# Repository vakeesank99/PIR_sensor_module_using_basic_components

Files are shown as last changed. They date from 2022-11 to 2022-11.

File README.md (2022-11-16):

# PIR_sensor_module_using_basic_components

I try to make the PIR sensor module without using the commercial IC which has all the functionality such as normal-mode, re-triggering and turned on only at the dark environment. This is very hard to understand the real concept behind each task as well as their implementation. But somehow we managed to proceed with all their required functionalities using transistors, OPAM and basic components. 

### Here is the schematic

Signal conditioning unit

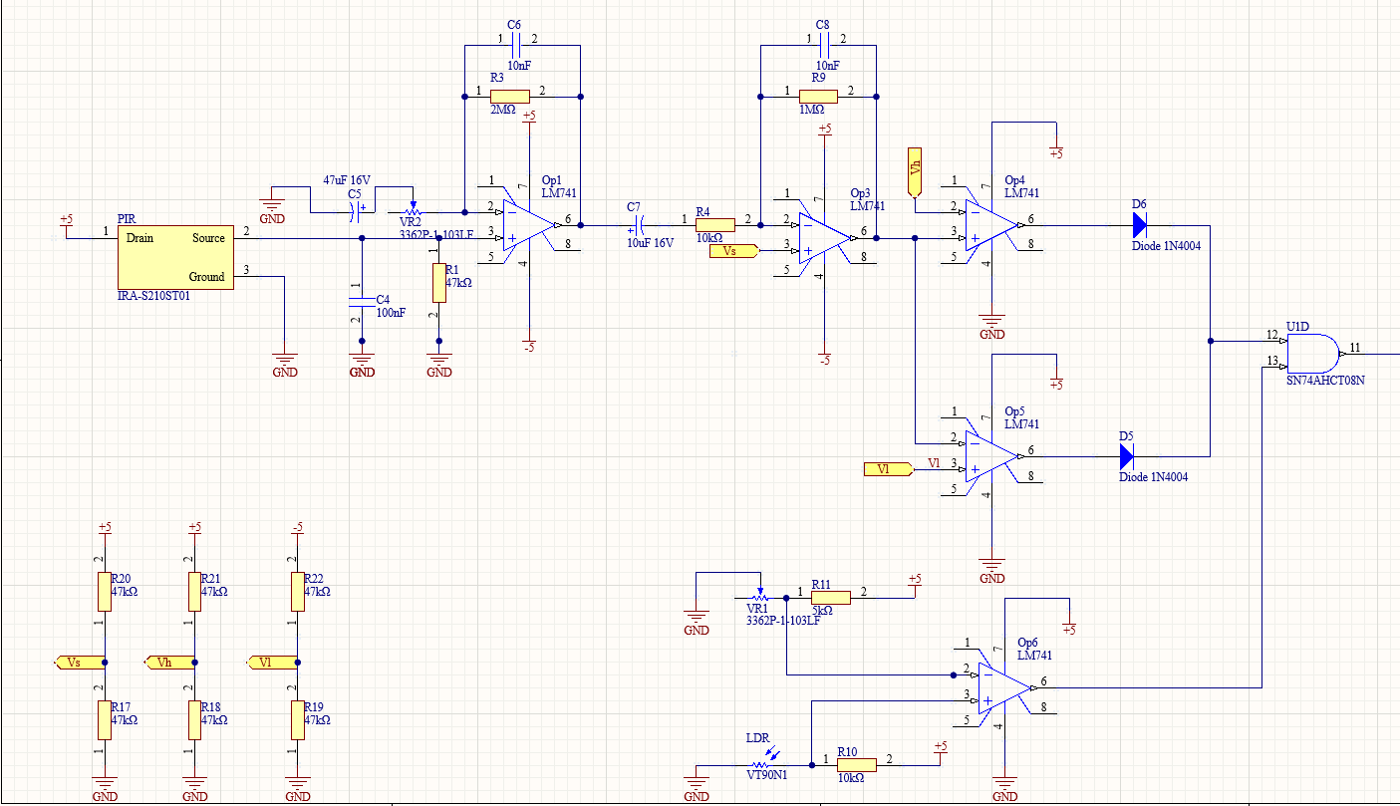
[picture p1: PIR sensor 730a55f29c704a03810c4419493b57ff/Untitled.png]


Decision making unit

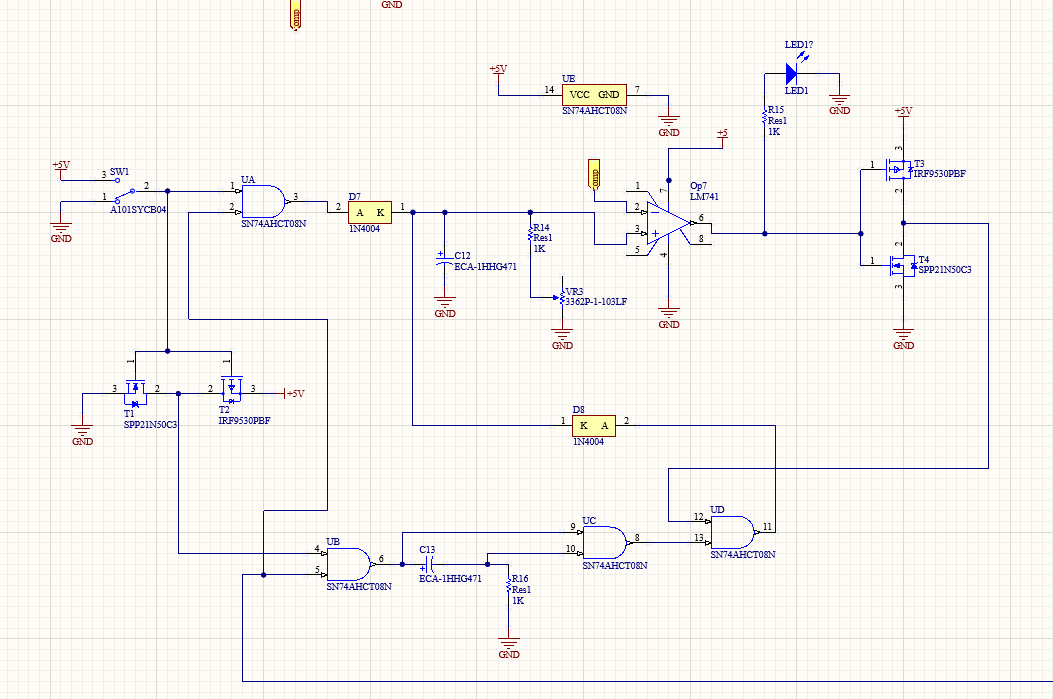
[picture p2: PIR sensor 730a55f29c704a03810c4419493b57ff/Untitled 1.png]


### Here is the final PCB after soldered the components.

Front



Back



### Appendix

Pyroelectric infrared sensors, IRA series, exhibit high
sensitivity and reliable performance made possible by
Murata's ceramic technology and Hybrid IC technique
expertise developed over many years.

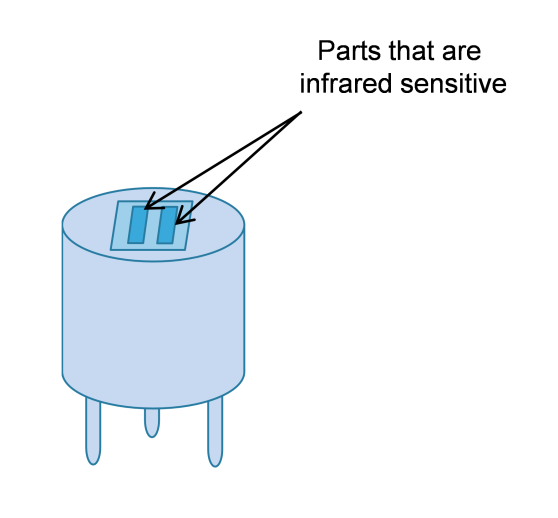
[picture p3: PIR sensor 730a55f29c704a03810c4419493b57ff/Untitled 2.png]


How does the PIR sensor work
The aim of the PIR sensor is to detect motion in a specific area. As seen in Figure 1: "PIR
sensor", these sensors contain two parts that are sensitive to IR. Since it is motion that is
important, the signal delivered by the sensor reflects different amounts of IR detected by
each part. If both parts "see" the same amount of IR, the sensor detects nothing. But, if one
of the two parts "sees" more or less IR than the other part, the sensor detects something
and the output voltage of the sensor varies.
Figure 2 shows how the output voltage varies when a heat source moves in or out of the
area protected by a sensor.

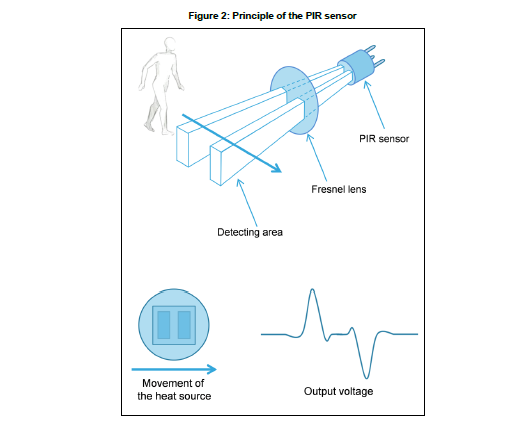
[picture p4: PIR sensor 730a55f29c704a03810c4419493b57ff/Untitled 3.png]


The area of the two rectangles that is IR sensitive is small (≈2 mm² for each rectangle).
Clearly, it would be better to increase the IR sensitive area. This can be done in two ways:
- by increasing the number of sensors
- by using a Fresnel lens
The latter method is highly recommended as it is inexpensive and improves IR reception by
the sensor. It multiplies the area visible to the sensor and it focuses reception of IR by the
sensor.

Three-stage architecture for detecting motion
To detect motion, a three-stage architecture based on op-amps is used to condition the
signal of a PIR sensor. This architecture is explained below.

### Stage 1
The first architectural stage amplifies the signal. It cancels the DC part of the signal and
filters the high frequency noise that could lead to false detections. The schematic of this
first architectural stage is shown in Figure 3.

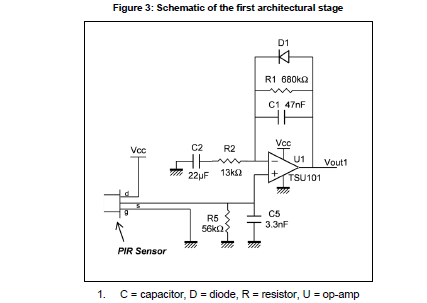
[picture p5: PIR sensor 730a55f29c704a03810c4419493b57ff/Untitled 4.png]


Figure 3 shows that noise is filtered thanks to the components R1 and C1. The cut-off
frequency is 5 Hz (fhigh1 = 1/(2 x π x R1 x C1)). This application does not need to work at
higher frequencies because usually we are detecting human motion.
The second filter is used to reject the DC part of the signal. R2 and C2 perform a high pass
filter that has a cut-off frequency of 0.6 Hz (flow1 = 1/(2 x π x R2 x C2)).
Since we do not amplify the DC part of the signal, the Vio, which is the input offset voltage
of the op-amp, has no importance in this application.
The stage gain is 53.3 (Gain1 = 1 + R1/R2). This amplification allows a usable signal that is
higher than the noise level. The DC bias of the first architectural stage is determined by the
sensor. To avoid saturation, the gain must not be too big because amplification is made
around this common mode voltage (which is not Vcc/2).
STMicroelectronics’ TSU101 op-amp is a perfect fit for this architectural stage. As well as
having very low consumption, the TSU101 operates with a typical current consumption of
only 600 nA at Vcc = 3.3 V.
The diode, D1, is explained in Section 5: "Power-up".

### Stage 2

Stage 2 is very similar to stage 1 (see Figure 4). It is used to filter and amplify the AC
signal.

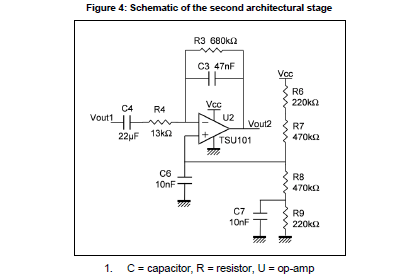
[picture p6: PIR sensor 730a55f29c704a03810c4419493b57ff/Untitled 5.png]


Regarding the filtering function, the low and high cut-off frequencies respectively are 0.6 Hz
(flow2 = 1/(2 x π x R4 x C4)) and 5 Hz (fhigh2 = 1/(2 x π x R3 x C3)). The gain of this stage is
-52.3 (Gain2 = -R3/R4). This gain means that after stage 2 the signal between 0.6 Hz and
5 Hz will have been amplified 2790 times (69 dB).
In stage 2, the op-amp common mode voltage is set by the divider bridge composed of R6,
R7, R8, and R9 to Vcc/2. This allows greater amplification of the AC signal.
As with stage 1, the Vio of the op-amp has no importance since the DC part of the signal is
not amplified. Moreover, there is no constraint on the gain bandwidth product (GBP),
because the op-amp has to have a GBP greater than 2.6 kHz (fhigh2 x gain x 10). A factor of
10 has been used to avoid any limitations by the GBP. Almost all GBP amplifiers fit this
2.6 kHz requirement.
The TSU101 op-amp is very suitable for this architectural stage. Its low consumption is
particularly advantageous. Although it is a nanopower op-amp, its GBP is higher than
2.6 kHz. Note that TSU101 is also available in dual (TSU102) and quad (TSU104) channel
versions to optimize the footprint on board.

### Stage 3

The third and last architectural stage allows the user to perform a window comparator. As a
consequence, the signal is perfectly conditioned to go to a microcontroller. Figure 5 shows
the schematic of this stage.

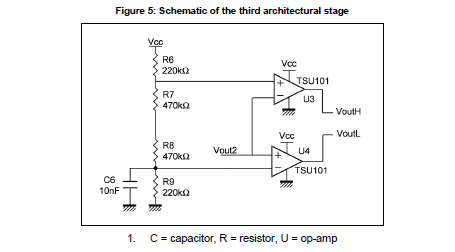
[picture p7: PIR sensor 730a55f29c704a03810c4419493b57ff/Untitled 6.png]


When a heat source is detected, the output of the op-amp U3 and/or U4 is in low state. The
divider bridge, composed of the resistors R6, R7, R8, and R9, is used to set the voltage
reference of these devices. The TSU101 op-amp is an input/output rail to rail op-amp, and
there is no constraint on the input common mode voltage. Thus, while the voltage
references of U3 and U4 are within the Vcc range the window comparator works.
For the following example, the reference of U3 is set to 0.84 * Vcc:



When the signal (Vout2) is above this reference (2.77 V if Vcc = 3.3 V), the output of U3 is
in low state, close to ground.
U4 is used to detect when the signal is below a certain reference. In this example, the
voltage reference is set to 530 mV thanks to the divider bridge composed of R6, R7, R8, and
R9. The voltage reference calculation is:



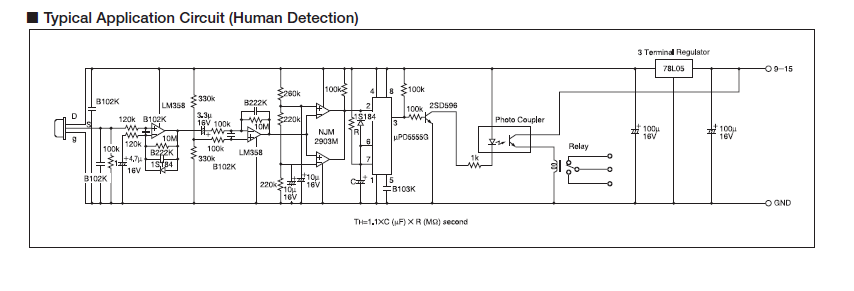
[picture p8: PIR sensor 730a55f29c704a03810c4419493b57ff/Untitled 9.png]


window comparator

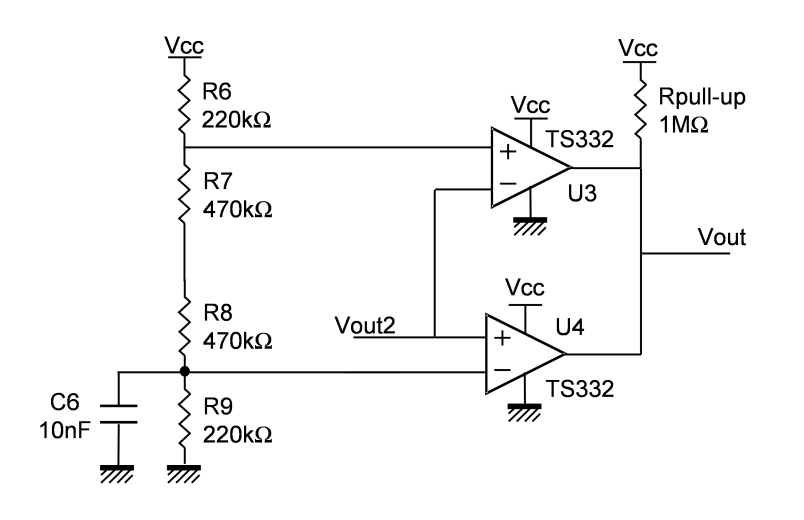
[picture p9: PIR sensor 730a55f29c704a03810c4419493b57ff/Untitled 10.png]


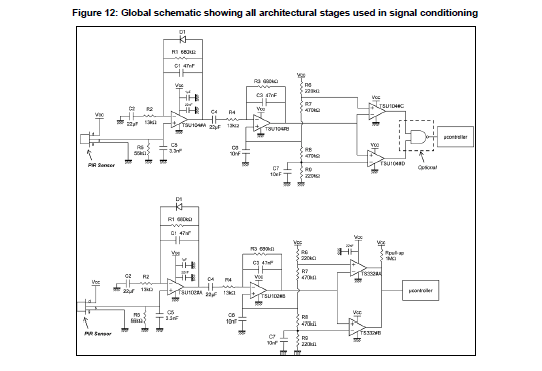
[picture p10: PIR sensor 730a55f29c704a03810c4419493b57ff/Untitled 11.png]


offset null procedure

[https://www.youtube.com/watch?v=5ExpeE_YOwQ](https://www.youtube.com/watch?v=5ExpeE_YOwQ)

[https://www.youtube.com/watch?v=Ut-m8dl7INA](https://www.youtube.com/watch?v=Ut-m8dl7INA)

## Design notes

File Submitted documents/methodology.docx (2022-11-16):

Methodology

Amplifier part

when there is an object with a temperature different than ambient temperature, is moving in front of the PIR sensor which emits a small Ac signal around 1 mVpp. as our task to detect the human motion, we need to consider the frequencies from 0.5 Hz to 10 Hz. further more that signal will be around a DC level which is significant sensor to sensors.

therefore, it is mandatory to cancel out the DC part of the signal then the AC part of the signal should be amplified. As the signal has the environment effect, Nosie filtering will be useful as well. the Op amps are very helpful to achieve for all these functions. we can divide the amplifier part into four sub parts.

stage 01

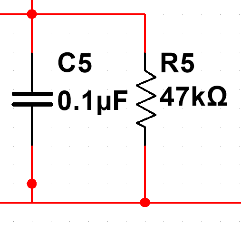
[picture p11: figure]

from the PIR sensor

to the op amp 1

At the first PIR sensor’s signal will go through the C5, R5 (first order filter). here we can see that it will act like an LPF (Low Pass Filter). therefore, there will be an upper cut off frequency which can be calculated as below.

f_(upper cut off) =1/(2πR_5 C_5)=1/(2π×47 kΩ ×0.1 μF)≈34 Hz

As we have already known that our final task is to detect the human motion which is around 10 Hz such that it’s approximately taken the 34 Hz as the upper cut off which is not harm. Other than that, we can simply avoid the high frequency noises (not thoroughly) as well as the environmental effects at this simple stage.

stage 02

After that our signal will enter in to the next stage where we can cancel out the DC component by a capacitor. the smoothing circuit will get rid of the high frequency noise as well as, give the variable gain to accommodate the sensitivity at a certain level.

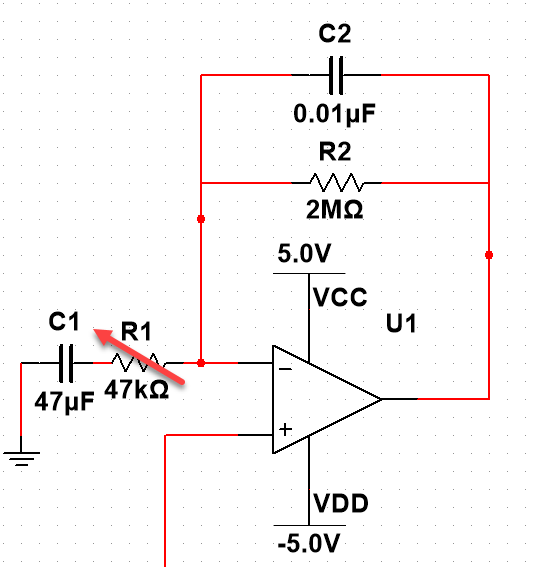
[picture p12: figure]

from the LPF part

to the op amp 2

as it’s explained above, C1 will cancel out the DC components from the sensor and allows the AC components of the signal. the value of the capacitor is taken same as the C5 in previous discussion without any particular reasoning. there will be a lower cut off value for the smoothing filter which can be calculated as shown below.

f_(lower cut off) =1/(2πR_2 C_2)=1/(2π×2 MΩ ×0.01 μF)≈8 Hz

According to the bode plot of the integrator circuit of the op amp, amplitude will be decreasing and smoothing will be started at the lower cut off point. it is calculated that at around 8 Hz circuit starts the smoothing functionality as well as the amplitude of the output signal is high (our requirement is at 10Hz so, no issues). Furthermore, as it’s mentioned earlier the gain of the is first op amp can be adjustable as shown below.

A_(op1) =-(R2)/(R1)

it is possible to set this gain as constant if we don’t want the distance as a variable. Such that it is assumed to set the gain from the first op amp as ~40. furthermore, R2 can be easily got from the R5 value and R2

R_5 =R_1 |R_2 =47 kΩ |2 MΩ≈47kΩ

but this value is only valid for the object which is moving nearby (< ~ 50cm) the PIR sensor. such that when it is increased to detect the object far from the previous value. therefore, the potentiometer value is selected as 1M ohm (quite reasonable). Furthermore, our input is an AC signal such that we have to supply a negative voltage to the op amp.

stage 03

After this part our signal again enter into a capacitor in order to avoid any DC components coming out from the op amp 1. Moreover, C3 is also chosen same as the previous discussion.

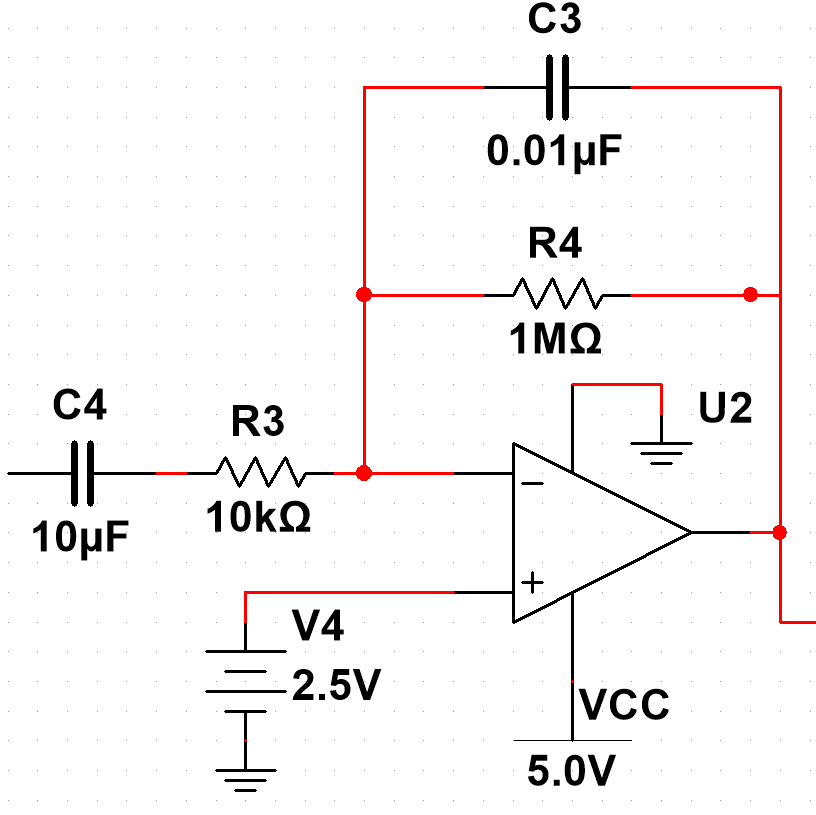
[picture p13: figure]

from the op amp 1

to the window comparator

In this circuit we can simply increase the gain by another amount. That can be calculated as below.

A_(op2) =-(R_4)/(R_3)=-(1MΩ)/(10kΩ)=-100

such that the total gain can be calculated by multiplying the two gain values. this is very important for the proper selection of R1 in the first op amp as well as maintaining the peak to peak amplitude of the signal at |2.5V| for the next stage.

The non-inverting voltage V4 is chosen to give the DC bias to the output signal from this part. this is useful when it comes to the window comparator. it’s efficient as well as good for the minimizing the error if we can utilize the VCC (5 V) as the peak to peak voltage such that whether the positive or negative part of the signal will be on the bias of VCC x 0.5 = 2.5V. That means our amplified signal will be on top of +2.5V bias voltage.

stage 04

Now we can look at the window comparator part.

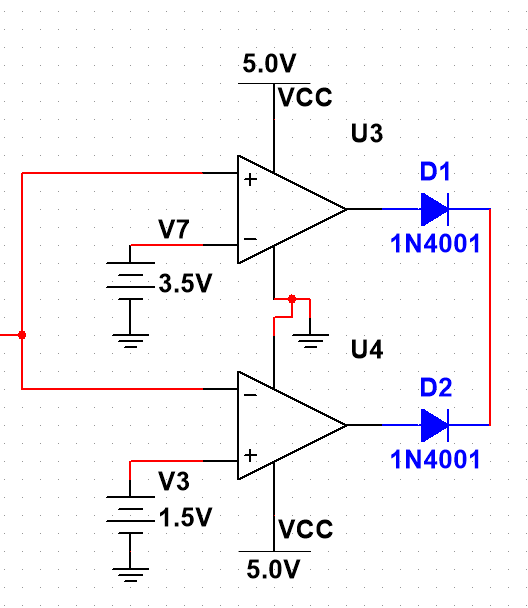
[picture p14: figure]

from the op amp 2

to the next stage

thresholding voltages are also selected to detect the signals at a perfect region as given below.

V_7 =VCC ×0.7=5×0.7=3.5 V

V_3 =VCC ×0.3=5×0.3=1.5 V

therefore, the voltages less than 1.5V or greater than 3.5V will inform as a motion. This is clearly explained in the given image.

After we add both signals by two diodes rather than connecting both signals directly to the next stage. because the diodes will stop the external voltage which is higher than the op amp’s output, enters into the op amp.

Here we are dealing with only the positive signal such that we don’t need to use negative supply to the window comparators.

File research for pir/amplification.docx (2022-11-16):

Intro for PIR and pyro electric sensor (can be omitted)

Infra-red sensors can be either active or passive. Active infrared sensors can work for a long distance, because the infra-red emitter and the sensor can be far apart. Passive infra-red sensor can be also be used to detect motion, using some sensitive sensors.

Passive infrared sensors detect the infra-red rays produced by an object. But active infrared sensors require an infra-red emitter to be the source of radiation. Pyroelectric sensor is an infra-red optoelectronic device is used to find electro-magnetic radiation from 2 to 14um of wave length.

Picture

With the infrared radiation, pyroelectric sensor’s crystal heats and surface charge increases. However, the charge is quite low. But the adequate FET or OpAmp circuit can convert the charges into a voltage pulse. Response voltage will be around 4.6 mV and source voltage will be 0.2 to 1.5 V at room temperature. We can simply indicate the functional blocks inside the sensor.

Sensor→ amplifier→ comparator

Furthermore, this sensor shows a better S/N ratio up to modulation frequencies of 4kHz. Human and animals emits IR radiation strongest at 9.4um of wave length. In some sensors, there will be a filter that can allow 8 to 14um range which is very sensitive to the human bodies.

Feed into two stage amplification. Each of them has gain of 100 and total gain will be about 10000. The amplifier is typically band limited to below 10Hz to reject high frequency noise.

amplifier

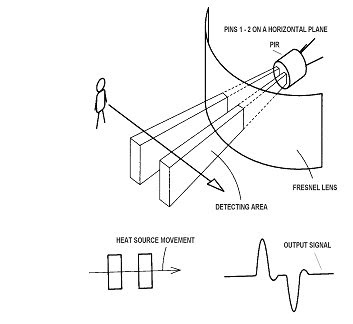
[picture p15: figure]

At first, we need to understand the fundamental operation of a pyroelectric sensor to implement in our PIR sensor. Figure 01 is exactly showing its function.

When a radiating object crosses the sensor, the infrared radiation from the object will hit on the sensor’s surface. Such that, it will create a positive pulse by its internal functions. Likewise, it will create a negative pulse when an object leaves the sensor. We need to amplify a small signal before it's provided to other functional blocks. Therefore, we decided to choose an amplifier block with desired gain. There can be several OpAmps or transistors to create the amplifier block for our project. We don’t have ideas about the OpAmp ICs and their part number yet. But it could be a challenging task for us to navigate through this amplifier block.

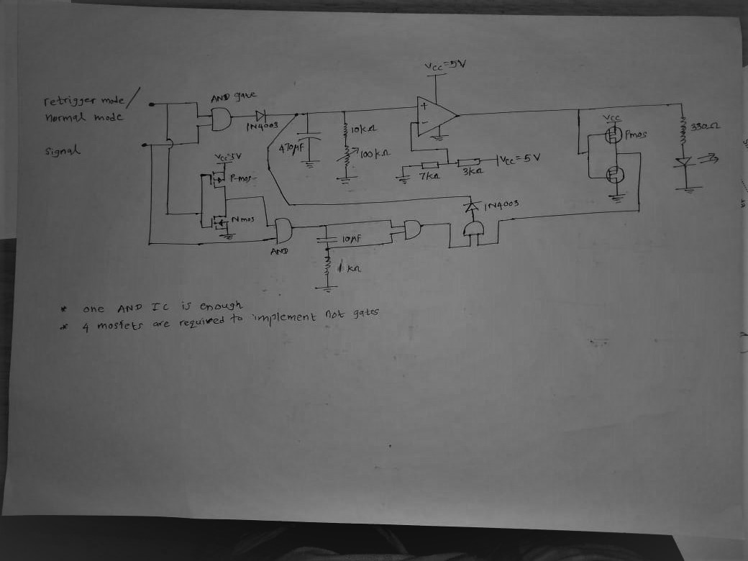
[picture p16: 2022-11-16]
research for pir/schematic 2.jpeg

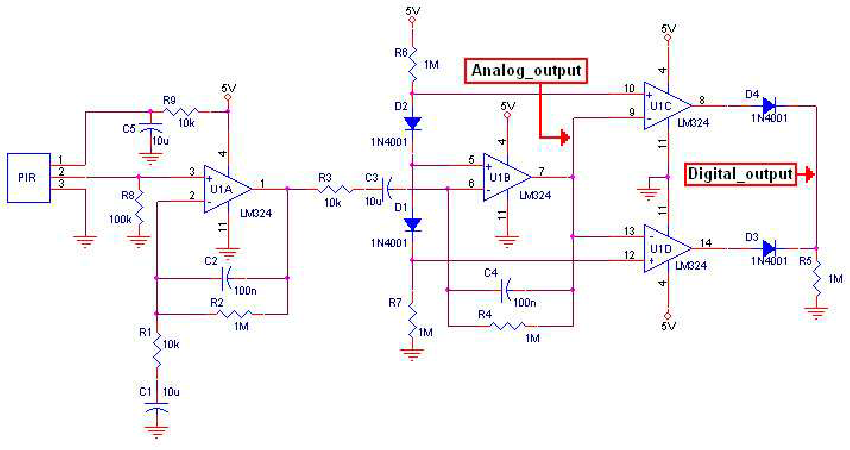
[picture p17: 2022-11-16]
research for pir/The-circuit-diagram-for-capturing-an-analog-signal-output-from-a-PIR-sensor.png

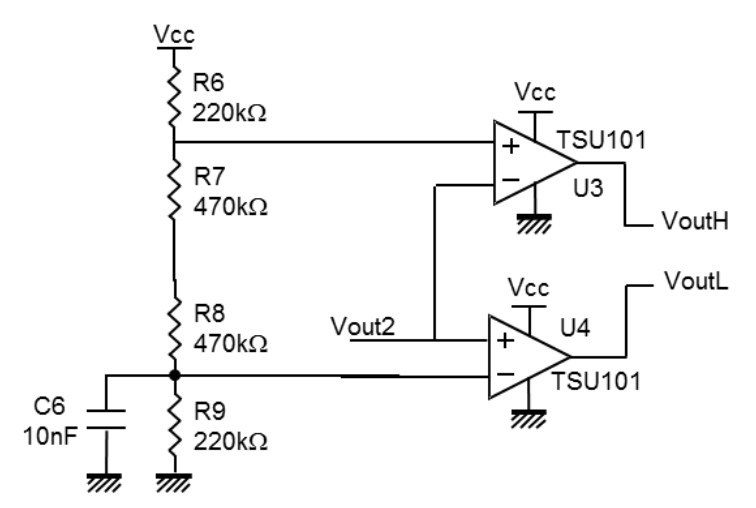
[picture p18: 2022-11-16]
research for pir/STMicro3.jpg

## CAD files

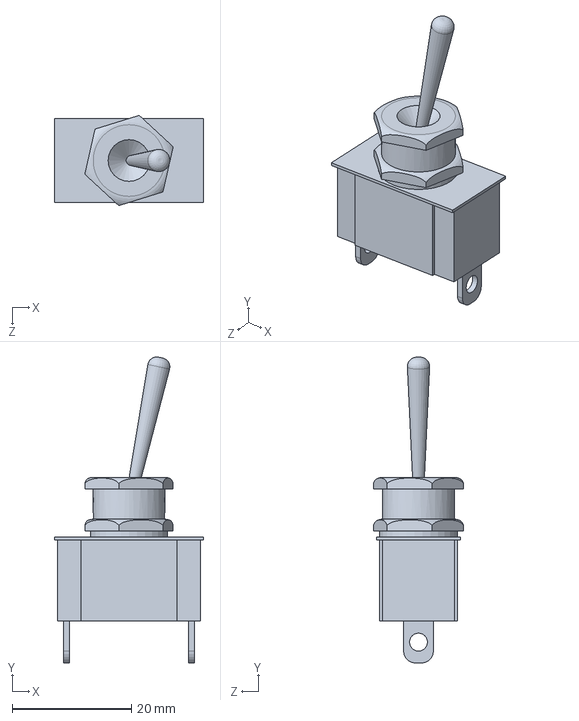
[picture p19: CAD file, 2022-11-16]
Enclosure/SPDT switch.SLDPRT
25.0 x 51.2 x 15.1 mm

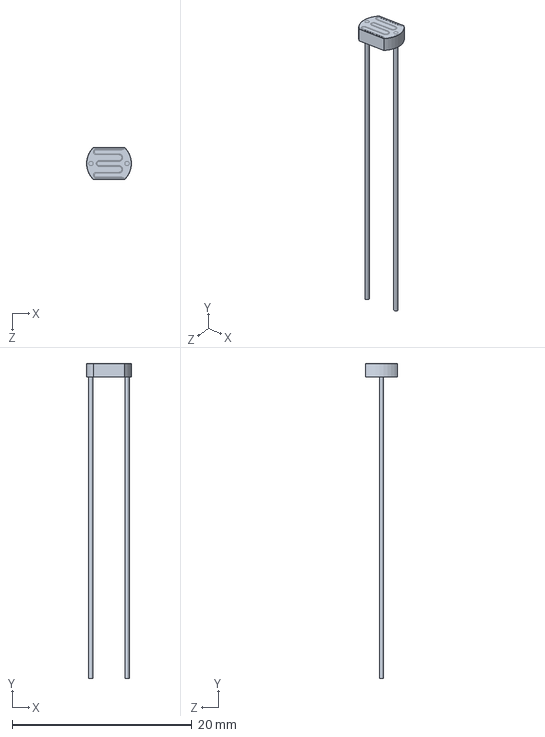
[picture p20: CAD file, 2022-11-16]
Enclosure/Part7.SLDPRT
4.98 x 35.0 x 3.60 mm

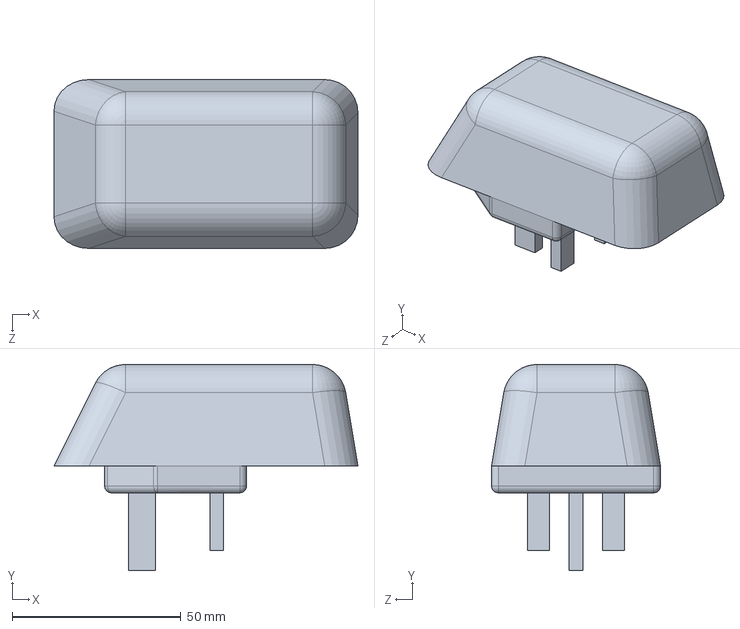
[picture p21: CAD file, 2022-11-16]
Enclosure/power.SLDPRT
90.0 x 61.0 x 50.0 mm

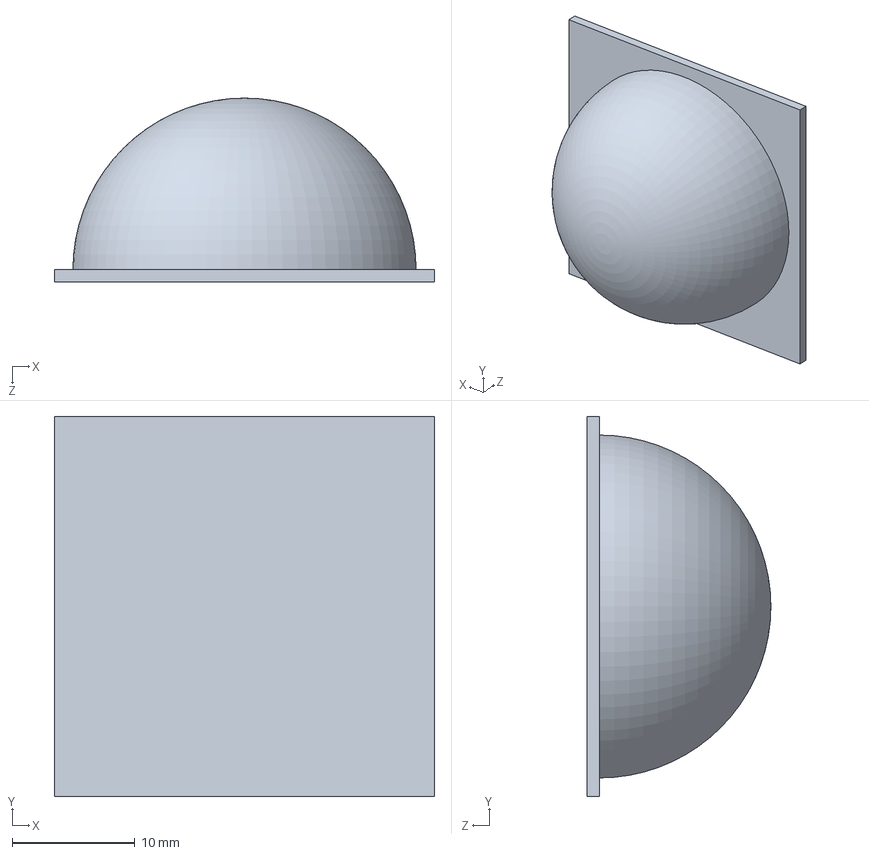
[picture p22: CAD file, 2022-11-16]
Enclosure/lense.SLDPRT
31.0 x 31.0 x 15.0 mm

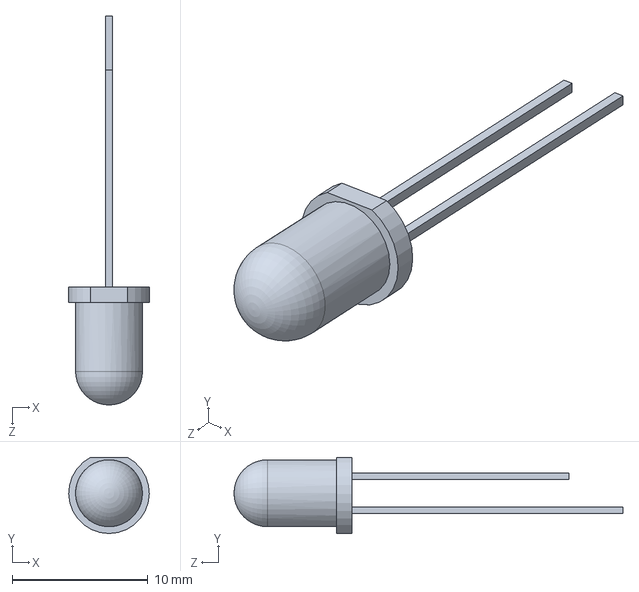
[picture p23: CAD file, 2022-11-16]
Enclosure/red-led-5mm.SLDPRT
5.95 x 5.62 x 28.7 mm

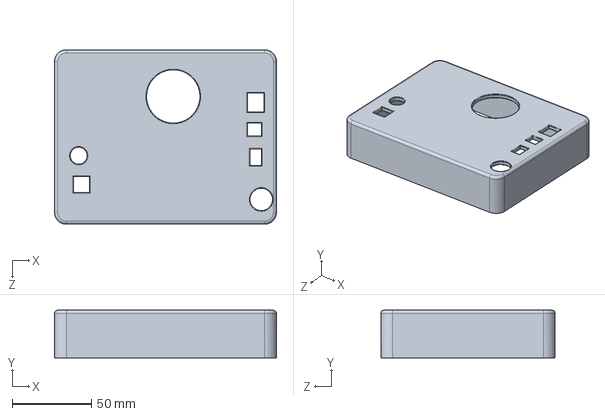
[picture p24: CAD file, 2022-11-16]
Enclosure/PIRPart1.SLDPRT
140.0 x 30.0 x 110.0 mm

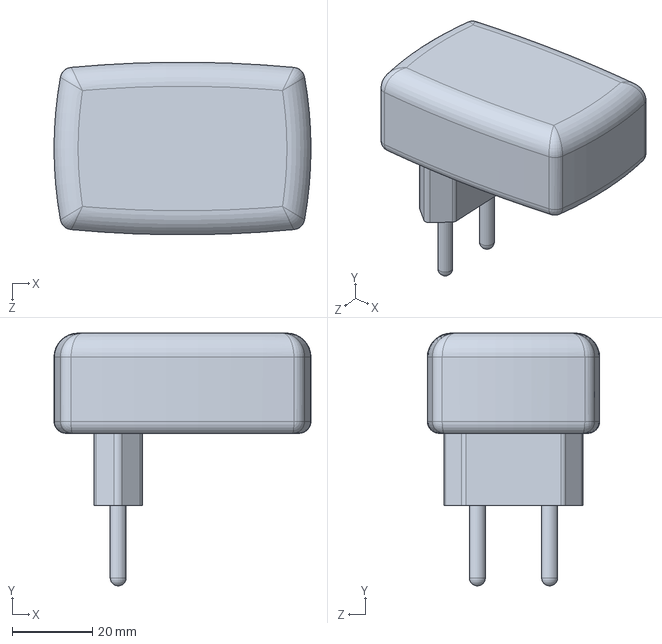
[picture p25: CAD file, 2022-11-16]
Enclosure/charger 2.SLDPRT
64.0 x 63.0 x 43.0 mm

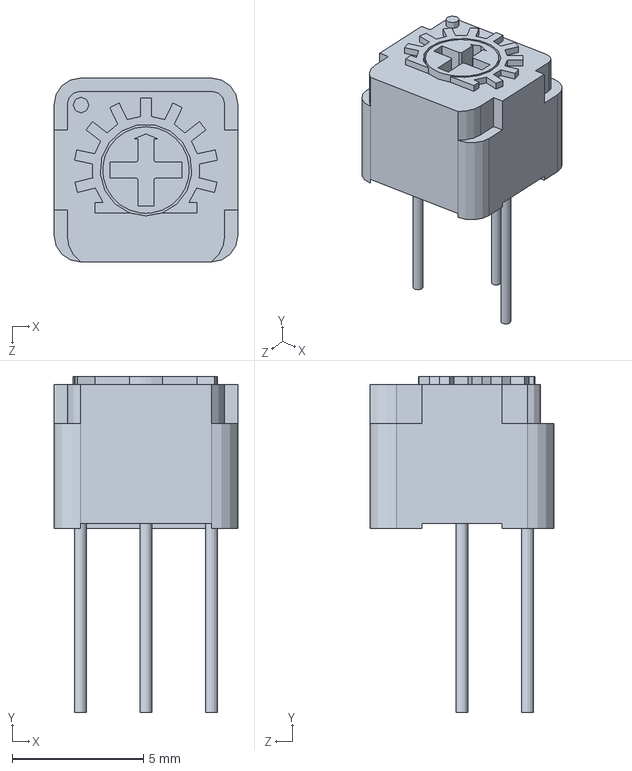
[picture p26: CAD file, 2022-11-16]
Enclosure/TrimmerPot.SLDPRT
7.00 x 12.8 x 7.00 mm

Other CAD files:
Enclosure/PIRPart1_.SLDPRT

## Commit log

2022-11-16 Add enclosure files
    [PIRPart1.SLDPRT, PIRPart1_.SLDPRT, Part7.SLDPRT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]
2022-11-16 Create PCB
2022-11-16 Add PCB files
    [PCB1.PcbDoc, PIR_Power_Supply.PrjPcb, Sheet1.SchDoc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]
